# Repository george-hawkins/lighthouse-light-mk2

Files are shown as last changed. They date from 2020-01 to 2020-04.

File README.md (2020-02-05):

Lighthouse light mark 2
=======================

This project covers a mechanical alternative to my earlier [lighthouse light project](https://github.com/george-hawkins/lighthouse-light).

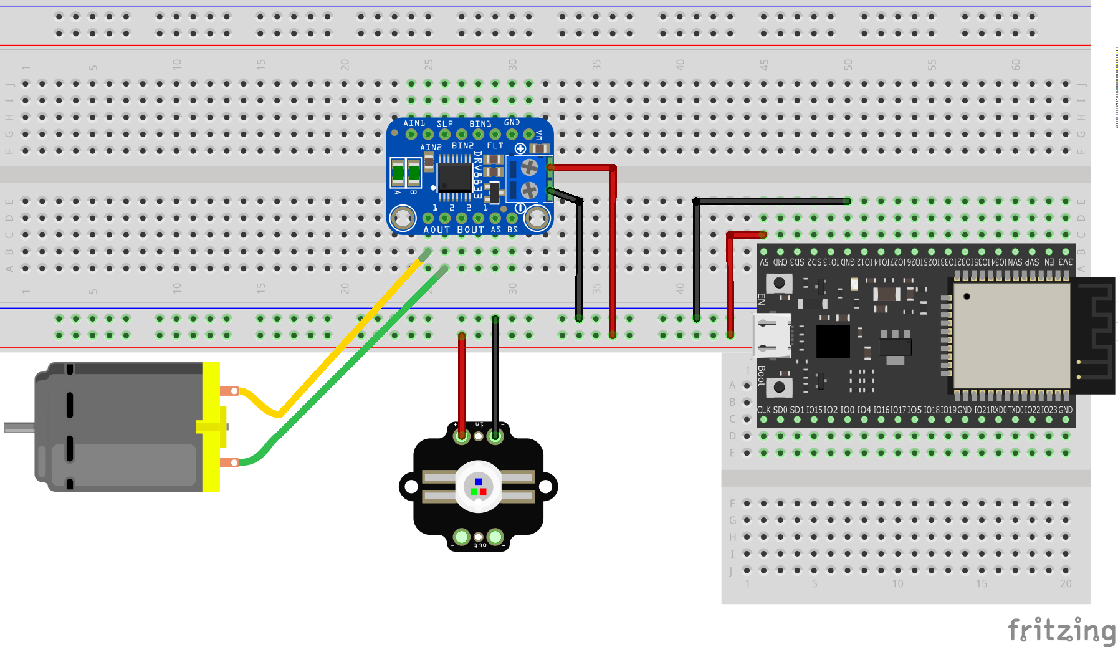
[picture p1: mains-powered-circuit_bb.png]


The [Fritzing](https://fritzing.org/home/) file for this circuit is [here](mains-powered-circuit.fzz).

Note: the Fritzing part for the ESP32-DevKitC was created by Hideaki Tominaga and can be found [here](https://ht-deko.com/delphiforum/?vasthtmlaction=viewtopic&t=1971.0#postid-3341).

Unfortunately, the ESP32-DevKitC is too wide to be mounted on a single standard breadboard - hence the need for the arrangement above where a smaller additional breadboard is used alongside the main one.

Misc
----

Also here, you can find:

* My [parts page](parts.md) for the main project here (and for the 3W RGB LED hookup and for a high current LiPo setup).
* My [hookup guide](3w-rgb-led-hookup-guide.md) for the Adafruit [3W RGB common anode LED](https://www.adafruit.com/product/2530).
* A [CSV file](digikey-leds-by-lumens.csv) of all the standard through-hole [discrete LEDs](https://www.digikey.com/products/en/optoelectronics/led-indication-discrete/105) that Digikey normally stock. Digikey just lists candella and viewing angle values for these LEDs, this CSV file includes a lumens value (calculated from the candella and angle values). The columns are _lumens_, _part number_, _millicandella_ and _viewing angle_. Some of the Digikey provided values appear to be wrong so you should double check any values in the relevant datasheet.
* My [guide](batteries.md) to batteries and in particular choosing parts for a setup where a lot of current is required.

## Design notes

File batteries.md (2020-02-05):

TLDR; if you want to draw more current, than supplied by the hobbyist li-ion cells from Adafruit and Sparkfun, then use a branded 18650 cell with a high C reading and built-in protection circuit along with a battery holder designed to accommodate the non-standard height of such cells.

---

Li-ion batteries are a borderline hobbyist component. Many electronics projects include a jokey disclaimer to the effect that the thing in question _may_ burn your house down. Li-ion batteries, if not handled correctly, definitely will burn your house down.

Li-ion batteries are inconventient to handle and inconventient to dispose of responsibly - but they can provide more power classic NiMH rechargeables (and don't suffer from the [memory effect](https://en.wikipedia.org/wiki/Memory_effect)).

However they're quite different from classic non-rechargeable alkaline batteries and NiMH rechargeables. These classic batteries don't need any supporting electronics and can be mishandled without any real dire consequences. Li-ion batteries in contrast will go on fire if mishandled and require a protection circuit to function safely.

The protection circuit typically do several things - it provides overcharging, overheating, shorting and undervoltage protection.

Overcharing, overheating and shorting will cause the battery to puff up (due to the build up of gasses within the cell) and eventually to catch fire.

Undervoltage in contrast is protecting the battery from you - with classic NiMH rechargeables you can just use them until they stop working and then recharge them. Li-ion batteries have a _nominal_ voltage of 3.7V, however when fully charged they provide about 4.2V - the voltage drops as the battery discharges. Eventually it'll reach 3V - if the voltage is allowed to drop below this point the battery will reach a state from which it cannot be charged.

The least consumer safe li-ion batteries are those used by [RC](https://en.wikipedia.org/wiki/Radio-controlled_model) hobbyists. These come wihout protection circuit or any kind of protective casing. It's up to separate circuitry in the RC vehicle to monitor the state of the battery.

In contrast the li-ion cells sold by hobbyist sites like Adafruit and Sparkfun come with a protection circuit as part of the battery. But with the exception of 18650 based cells (which we'll come to), they don't have any protective casing.

Finally the most consumer safe li-ion batteries are the powerbanks that you find everywhere for providing reserve power for your mobile phone and other portable consumer electronic devices. The li-ion cells are protected by a hard plastic case and the electronics provide the fixed 5V, that USB devices require, and limit the current.

These batteries may be safe and convenient but they're the least flexible for hobbyist projects. The fixed voltage, limited current and non-standard sizes don't make them great to work with (though you do find them being used in cheap robot projects. This [JetBot kit](https://www.sparkfun.com/products/15365) from Sparkfun uses one - but it also demonstrates the limitations of such powerbanks as the Nvidia Nano used in the project has to be run in a low-power mode due to the limited current, in contrast to this [JetBot kit](https://www.waveshare.com/jetbot-ai-kit-acce.htm) from Waveshare that uses 18650 batteries and can run the Nano at full power.

Most of the li-ion batteries provides by hobbyist sites come in completely non-standard shapes - the exception are those based on what are called [18650 cells](https://en.wikipedia.org/wiki/List_of_battery_sizes#Cylindrical_lithium-ion_rechargeable_battery).

If you crack open (not recommended) a powerbank you'll find it full of 18650 cells and if you crack open a Tesla battery pack you'll find more the 7 thousand of them.

They come in a standard form factor similar but larger than a classic AA battery. While they have a standard shape there are no end of variations with different [C ratings](https://oscarliang.com/lipo-battery-c-rating/) and different [mAh capacities](https://oscarliang.com/lipo-battery-guide/#capacity).

These cells aren't typically sold directly to consumers and, like all li-ion batteries, their tendency to catch fire is mishandled makes them very unpopular with postal services, e.g. the UK postal service will destroy your whole package if they find it contains loose li-ion cells, i.e. cells that are not built into or attached to an electronic device).

This makes them quite hard to buy. Most sites don't want to deal with the extra postage issues involves and even big electronic component sites like Mouser or Digikey, that carry every conceivable variant of everything else, don't really stock such batteries (they do sell a few as they act as distributors for the cells sold by Adafruit and Sparkfun and a few other hobbyist sites).

---

You can easily stick a thumb-tack into such a cell, shorting the internal layers and causing it to catch fire.

So you end up having to buy them from specialist sites.

They're heavily counterfieted, i.e. cheap no-name Chinese cells are repackaged to look like branded cells from Samsung etc. (whose cells look very generic anyway).

Manufacturers generally bundle unprotected cells together into packs and then provide protection and recharging circuitry for the full pack.

When using boards like the Adafruit [Feathers](https://www.adafruit.com/category/946) the recharging circuitry is provided by the board but you still need a protected cell.

So while 18650 cells are generally sold unprotected, you can buy them with a tiny [disc shaped protection circuit](https://www.banggood.com/1S-3_7V-18650-Lithium-Battery-Protection-Board-2_5A-Li-ion-BMS-with-Overcharge-and-Over-Discharge-Protection-p-1529056.html) attached to the base.

---

Spot welding - DIY

[Sunkko 737G 220V spot welding machine](https://www.banggood.com/SUNKKO-737G-220V-Battery-Spot-Welding-Hand-Held-Welding-Machine-with-Pulse-Current-Display-p-1310562.html) - US$110 from Banggood.

Battery holder - protected / unprotected.

Samsung Note, no-name hoverboards.

While many people do successfully build their own battery packs without apparent issue, the consensus seems to be that applying extreme heat, even momentarily, to something as already temperamental as a li-ion battery isn't recommended.

Buying the protection board separately gives you more flexibility - you can use any unprotected cell - but you have to make sure to match the maximum discharge current of the board to the the maximum discharge current supported by the cell.

MakeUseOf has a nice [introductory page](https://www.makeuseof.com/tag/18650-battery/) for 18650 batteries.

---

Memory Protection Devices (MPD) provide battery holders designed for protected 18650 cells:

* [BH-18650-PCD](https://www.digikey.com/product-detail/en/mpd-memory-protection-devices/BH-18650-PC/BH-18650-PC-ND/3029216) - battery holder without leads.
* [BH-18650-W](https://www.digikey.com/product-detail/en/mpd-memory-protection-devices/BH-18650-W/BH-18650-W-ND/3029217) - battery holder with leads.
* [BK-18650-PC2](https://www.digikey.com/product-detail/en/mpd-memory-protection-devices/BK-18650-PC2/BK-18650-PC2-ND/2079908) - battery holder with tabs to hold battery in-place and without leads.

The above links are to Digikey - these battery holders are available from many other suppliers, e.g. [Reichelt](https://www.reichelt.com/ch/en/Battery-holder-for-other-types-of-batteries/2/index.html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) (just select Memory Protection Digikey under the manufacturer filter).

Banggood knockoff of MPD battery holder for *protected* 18650, [with leads](https://www.banggood.com/DIY-1-Slot-18650-Battery-Holder-With-2-Leads-p-972775.html) and [without leads](https://www.banggood.com/DIY-Storage-Box-Holder-Case-For-1-x-18650-Rechargeable-Battery-p-1006063.html).

Adafruit [JST PH 2-pin 100mm cable with female connector](https://www.adafruit.com/product/261) or, if you need something longer, their [JST PH extension cable](https://www.adafruit.com/product/1131) (just chop off the unneeded end).

Banggood [Battery holder](https://www.banggood.com/1-Slots-18650-Battery-Box-Rechargeable-Battery-Holder-Board-for-1x18650-Batteries-DIY-kit-Case-p-1472104.html) for *unprotected* 18650.

Banggood [NCR18650B 3.7V 3400mAh protected 18650 battery](https://www.banggood.com/1PCS-NCR-18650B-3_7V-3400mAh-Protected-Rechargeable-Lithium-Battery-p-90678.html).

* AkkuShop Schweiz [NCR18650B 3400mAh protected 18650](https://www.akkushop-schweiz.ch/ch/panasonic-18650-li-ion-akku-mit-3400mah-und-eigener-schutzschaltung-ca.-68-x-18mm-beachten/) - Fr. 30.
* AkkuShop Schweiz [NCR18650B 2900mAh protected 18650](https://www.akkushop-schweiz.ch/ch/panasonic-ncr18650-pf-2900mah-pcb-geschuetzt/) - Fr. 26.
* Conrad DE [NCR18650B 3400mah protected 18650](https://www.conrad.de/de/p/panasonic-ncr18650b-spezial-akku-18650-li-ion-3-7-v-3400-mah-1009507.html) - EUR 19 (not listed on conrad.ch).

18650 Battery Store protected 18650 batteries:

* [Panasonic NCR18650B 3400mAh 4.9A](https://www.18650batterystore.com/Protected-p/panasonic-18650-protected.htm) - US$7.
* [Samsung 35E 18650 3500mAh 8A](https://www.18650batterystore.com/Samsung-18650-p/samsung-35e-protected.htm) - US$7
* [Sanyo NCR18650GA 3500mAh 10A](https://www.18650batterystore.com/Sanyo-18650-p/ncr18650ga-protected-pcb.htm) - US$8
* [Samsung 30Q 18650 3000mAh 15A](https://www.18650batterystore.com/Samsung-18650-p/samsung-30q-protected-pcb.htm) - US$9.

Note: in their [battery guide](https://www.18650batterystore.com/Best-18650-Battery-Guide-s/142.htm), the NCR18650B is described as "one of the best batteries on the market". However this page also lists the CDR (Continuous Discharge Rating) for every common 18650 battery and there you can see that the NCR18650B has the lowest CDR value - so if you need more than 5A, you'll need one of the other batteries.

See also [IMR Batteries](https://www.imrbatteries.com/18650-batteries/) for these 18650 batteries.

The easiest available source of protected 18650 batteries for consumers are 18650 batteries intended for use in flashlights, e.g. [Nitecore batteries](https://www.nitecorestore.com/18650-batteries-s/2532.htm). However these tend to be suprisingly expensive (and some of them come with odd feature like a USB port for direct charging).

Aliexpress TZT 1S boards:

* [3A](https://www.aliexpress.com/item/32803639402.html)
* [5A](https://www.aliexpress.com/item/32809288456.html)
* [7.5A, 10A and 15A](https://www.aliexpress.com/item/32956094047.html) - select 3MOS for 7.5A, 4MOS for 10A and 6MOS for 15A.

Banggood 1S boards:

* [2A](https://www.banggood.com/1S-3_7V-2A-li-ion-BMS-PCM-18650-Battery-Protection-Board-PCB-for-18650-Lithium-ion-li-Battery-p-1538099.html)
* [4A](https://www.banggood.com/1S-3_7V-4A-li-ion-BMS-PCM-18650-Battery-Protection-Board-PCB-for-18650-lithium-Battery-Double-MOS-p-1538089.html)

eBay:

* [1A to 12A](https://www.ebay.co.uk/itm/1S-Cell-PCB-BMS-18650-Protection-Board-Li-ion-Lithium-Battery/173955620419) - ships from UK.
* [5A, 10A and 15A](https://www.ebay.co.uk/itm/5-10-15A-1S-3-7V-18650-MOS-Li-ion-Lithium-Battery-Charging-BMS-Protection-Board/283300258134) - ships from China.

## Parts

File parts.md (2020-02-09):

Parts
=====

### 3W RGB common anode LED hookup

| Description | Quantity | Adafruit | Mouser | Digikey |
|---|---|---|---|---|
| 3W RGB common anode LED | 2 | [$3](https://www.adafruit.com/product/2530) | [$3](https://www.mouser.com/ProductDetail/485-2530) | [$3](https://www.digikey.com/product-detail/en/adafruit-industries-llc/2530/1528-2777-ND/9770538) |
| IRLB8721 N-channel power MOSFET | 3 | [$1.75](https://www.adafruit.com/product/355) | [$0.85](https://www.mouser.com/ProductDetail/942-IRLB8721PBF) | [$0.85](https://www.digikey.com/product-detail/en/infineon-technologies/IRLB8721PBF/IRLB8721PBF-ND/2127670) |
| ULN2803A - 8-channel Darlington driver | 1 | [$2](https://www.adafruit.com/product/970) | [$1.20](https://www.mouser.com/ProductDetail/511-ULN2803A) | [$1.20](https://www.digikey.com/product-detail/en/stmicroelectronics/ULN2803A/497-2356-5-ND/599591) |
| 5W 5&ohm; potentiometer | 1 | n/a | [$5.25](https://www.mouser.com/ProductDetail/774-026TB32R5A0B1A1) | [$5.25](https://www.digikey.com/product-detail/en/cts-electrocomponents/026TB32R5A0B1A1/CT2150-ND/203771) |
| 2W 5&ohm; resistor | 1 | n/a | [$0.20](https://www.mouser.com/ProductDetail/282-5.1-RC) | [$0.40](https://www.digikey.com/product-detail/en/yageo/FMP200JR-52-5R1/5.1ZCT-ND/2059023) |
| 2W 10&ohm; resistor | 1 | n/a | [$0.25](https://www.mouser.com/ProductDetail/282-10-RC) | [$0.35](https://www.digikey.com/product-detail/en/yageo/FMP200JR-52-10R/10ZCT-ND/2058964) |
| 2W 15&ohm; resistor | 1 | n/a | [$0.25](https://www.mouser.com/ProductDetail/282-15-RC) | [$0.35](https://www.digikey.com/product-detail/en/yageo/FMP200JR-52-15R/15ZCT-ND/2058972) |

Note: Yageo is Digikey and Xicon is Mouser - see the [AdaWiki partfinder](https://www.ladyada.net/wiki/partfinder).

### Shared

A 5V 2A power adapter, similar to this $7.50 [one](https://www.adafruit.com/product/1995) from Adafruit or pretty much any power adapter sold for the Raspberry Pi, must be 2A or more.

| Description | Quantity | Adafruit | Mouser | Digikey |
|---|---|---|---|---|
| 2200mAh 18650 Li-ion battery | 1 | [$10](https://www.adafruit.com/product/1781) | [$10](https://www.mouser.com/ProductDetail/485-1781) | [$10](https://www.digikey.com/product-detail/en/adafruit-industries-llc/1781/1528-1836-ND/5054543) |
| HUZZAH32 - ESP32 Feather Board | 1 | [$20](https://www.adafruit.com/product/3405) | [$20](https://www.mouser.com/ProductDetail/485-3405) | [$20](https://www.digikey.com/product-detail/en/adafruit-industries-llc/3405/1528-2181-ND/7244967) |

Similar [2600mAh 18650 battery](https://www.aliexpress.com/item/32822109986.html) from Aliexpress for $3.75.

Note that Mouser and Digikey will not ship li-ion batteries to retail customers in most regions or will apply restrictions (e.g. no air shipping).

### ESP32 alternatives

* $11 - [Olimex ESP32-DevKit-LiPo](https://www.olimex.com/Products/IoT/ESP32/ESP32-DevKit-LiPo/open-source-hardware).
* $21 - [SparkFun Thing Plus - ESP32 WROOM](https://www.sparkfun.com/products/15663).

There are no end of no-name ESP32 modules available on sites like Banggood and Espressif themselves produce the nice cheap [ESP32-DevKitC-32D](https://www.mouser.com/ProductDetail/356-ESP32-DEVKITC32D) - however the ESP32-DevKitC-32D and most of these other boards don't have a LiPo JST connector (and the no-name boards generally come with no documentation).

Note: the 32 is the original Espressif module, the 32D is the newer module and the 32U is the 32D with a connector for an external antennae rather than a builtin PCB antennae.

**Question:** the HUZZAH32 - ESP32 Feather Board provides separate Vbat and Vusb pins so you can easily construct a circuit that works off Vbat only. However the Olimex ESP32-DevKit-LiPo tries to be pin compatible with the ESP32-DevKitC-32D (which only supports power via 5V USB) - so, _if I read the schematic correctly_, you've just got the 5V input voltage pin and you'll either see 5V or 3.7V on this pin depending on whether you're using USB power or battery power. TODO: ask Olimex if there's anyway to construct a circuit such that you only get power via this pin if battery power is being used?

### Lighthouse mark 2

| Description | Quantity | Adafruit | Mouser | Digikey |
|---|---|---|---|---|
| Adafruit Pixie | 1 | [$15](https://www.adafruit.com/product/2741) |  [$15](https://www.mouser.com/ProductDetail/485-2741) | [$15](https://www.digikey.com/product-detail/en/adafruit-industries-llc/2741/1528-1538-ND/5804104) |
| Plastic gearbox motor - 200RPM | 2 | [$3](https://www.adafruit.com/product/3777) | [$3](https://www.mouser.com/ProductDetail/485-3777) | [$3](https://www.digikey.com/product-detail/en/adafruit-industries-llc/3777/1528-2589-ND/8687221) |
| Eccentric motor hub | 1 | [$1](https://www.adafruit.com/product/3880) | [$1](https://www.mouser.com/ProductDetail/485-3880) | [$1](https://www.digikey.com/product-detail/en/adafruit-industries-llc/3880/1528-2699-ND/9603622) |
| motor pulley | 1 | [$0.75](https://www.adafruit.com/product/3789) | [$0.75](https://www.mouser.com/ProductDetail/485-3789) | [$0.75](https://www.digikey.com/product-detail/en/adafruit-industries-llc/3789/1528-2602-ND/9342241) |
| DRV8833 motor driver breakout | 1 | [$5](https://www.adafruit.com/product/3297) | [$5](https://www.mouser.com/ProductDetail/485-3297) | [$5](https://www.digikey.com/product-detail/en/adafruit-industries-llc/3297/1528-1795-ND/6419360) |
| JST on/off switch | 1 | [$3](https://www.adafruit.com/product/3064) | [$3](https://www.mouser.com/ProductDetail/485-3064) | [$3](https://www.digikey.com/product-detail/en/adafruit-industries-llc/3064/1528-1679-ND/6022074) |
| motor mounting bracket | 1 | [$1.50](https://www.adafruit.com/product/3768) | [$1.50](https://www.mouser.com/ProductDetail/485-3768) | [$1.50](https://www.digikey.com/product-detail/en/adafruit-industries-llc/3768/1528-2593-ND/9092301) |

Alternative motor and wheel (use the wheel as a hub to which to attach things):

* $3.50 - [DC motor in micro servo body](https://www.adafruit.com/product/2941)
* $2.50 - [matching wheel for motor](https://www.adafruit.com/product/2744)

### JST cable assemblies

| Description | Quantity | Adafruit | Mouser | Digikey |
|---|---|---|---|---|
| 2-pin cable set | 1 | [$1.50](https://www.adafruit.com/product/2880) | [$1.50](https://www.mouser.com/ProductDetail/485-2880) | [$1.50](https://www.digikey.com/product-detail/en/adafruit-industries-llc/2880/1528-1596-ND/5875804) |
| 3-pin cable set | 1 | [$1.50](https://www.adafruit.com/product/1663) | [$1.50](https://www.mouser.com/ProductDetail/485-1663) | [$1.50](https://www.digikey.com/product-detail/en/adafruit-industries-llc/1663/1528-2108-ND/7035021) |
| 4-pin cable set | 1 | [$1.50](https://www.adafruit.com/product/578) | [$1.50](https://www.mouser.com/ProductDetail/485-578) | [$1.50](https://www.digikey.com/product-detail/en/adafruit-industries-llc/578/1528-1518-ND/5774321) |
| 5-pin cable set | 1 | [$1.50](https://www.adafruit.com/product/1664) | [$1.50](https://www.mouser.com/ProductDetail/485-1664) | [$1.50](https://www.digikey.com/product-detail/en/adafruit-industries-llc/1664/1528-2109-ND/7035022) |
| 6-pin cable set | 1 | [$1.50](https://www.adafruit.com/product/1665) | [$1.50](https://www.mouser.com/ProductDetail/485-1665) | [$1.50](https://www.digikey.com/product-detail/en/adafruit-industries-llc/1665/1528-2110-ND/7035023) |

I already have the 4 pin one.

There must be similar sets from companies other than Adafruit on Mouser and Digikey but I can't find them.

Servo cable extension (cut in two and use as an cable set) - [$2](https://www.adafruit.com/product/972).

Sugru family-safe black 3 pack:

* [$10](https://sugru.com/buy/family-safe-skin-friendly-formula-black-3-pack) direct from Sugru.
* [Fr. 10](https://www.galaxus.ch/en/s4/product/sugru-klebeknete-family-safe-3-stueck-schwarz-glues-12446856) from Galaxus.

Note: Sugru has a relatively short shelf life of 13 months so be aware of this when buying.

High-viscosity glue from a glue gun might be just as good for this project.

### Heatsinks

* [7x7x10mm heatsink](https://www.adafruit.com/product/1493) - $1 - plus [thermal tape](https://www.adafruit.com/product/1467) - $1.
* [14x14x8 heatsink with thermal tape](https://www.adafruit.com/product/3083) - $1.50

### Heat shrink tubing

* [40mm 1m clear (also other sizes, lengths and colors)](https://www.ebay.ie/itm/PVC-Heat-Shrink-Tubing-Wrap-RC-Battery-Pack-17mm-150mm-LiPO-NiMH-NiCd-UK/361275492238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) - GBP 2 - eBay UK based.
* [40mm 1m clear (also other sizes, lengths and colors)](https://www.ebay.ie/itm/17MM-103MM-Wide-PVC-Heat-Shrink-Tubing-Wrap-Lipo-Li-ion-NiCd-RC-Battery-Pack/390950012124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) - GBP 1 - eBay China based.
* [40mm 2m clear (also other sizes, lengths and colors)](https://www.ebay.ie/itm/17mm-103mm-PVC-Heat-Shrink-Tubing-Wrap-Lipo-Li-ion-Ni-MH-NiCd-RC-Battery-Pack/252489229777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) - GBP 1.60 - eBay China based.

### Power supplies

[Digikey 5V power adapters](https://www.digikey.com/products/en/power-supplies-external-internal-off-board/ac-dc-desktop-wall-adapters/130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)

[Mouser 5V power adapters](https://www.mouser.ch/Power/Power-Supplies/Plug-In-AC-Adapters/Wall-Mount-AC-Adapters/_/N-brwlvZscv7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)

Note: for whatever reason, Mouser will **not** ship power adapters to retail customers in the EU (and other countries).

[Raspberry Pi universal power supply](https://www.raspberrypi.org/products/raspberry-pi-universal-power-supply/) (comes with interchangeable plugs for all regions).

RS supply similar power adapters with region specific plugs, just go to [RS Components](https://www.rs-online.com/), choose your region (for North American, choose the Allied link rather than the RS link) and search for:

* T6717DV for a US style plug.
* T6716DV for an EU style plug.
* T6715DV for a UK style plug.

These are the standard Raspberry Pi power supplies and are available from many other online retailers - just search for the part numbers in Google shopping.

### Misc

* [DANIU 8 piece pliers set](https://www.banggood.com/8Pcs-Round-Beading-Nose-Pliers-Wire-Side-Cutters-Pliers-Tools-Set-p-1042930.html).
* [Stickers - 28 pieces](https://www.banggood.com/28pcs-Cartoon-Colourful-Reflection-DIY-Laser-Stickers-For-Suitcase-Skateboard-Laptop-Luggage-Sticker-p-1335114.html).
* [Riden UM34C USB voltage and current meter (with Bluetooth)](https://www.banggood.com/RIDEN-UM34UM34C-For-APP-USB-3_0-Type-C-DC-Voltmeter-Ammeter-Voltage-Current-Meter-Tester-p-1297185.html?ID=514816).

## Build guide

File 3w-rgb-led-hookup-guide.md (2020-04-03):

3W RGB LED hookup guide
=======================

This page covers hooking up the Adafruit [3W RGB common anode LED](https://www.adafruit.com/product/2530). Most devices, that sites like Adafruit and Sparkfun supply, can simply be powered directly from the MCU board that you're using in your project. However the 3W RGB LED is rather more complex to deal with as it draws significantly more power than an MCU board can supply.

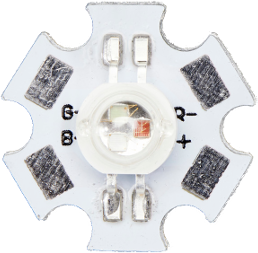
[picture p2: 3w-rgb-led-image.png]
3W RGB LED product image


TLDR; just jump to the breadboard diagram shown and set up the circuit shown making sure to use resistors with a suitable power rating.

---

Normally Adafruit has excellent hookup guides for all its parts, however all the guides for the 3W RGB LED involve using the [Prop-Maker FeatherWing](https://www.adafruit.com/product/3988) (which includes various other features, such as an amplifier and accelerometer). This "Wing" is designed to fit together with one of their [Feather series boards](https://www.adafruit.com/category/835). So it's not so clear how to hookup the 3W RGB LED directly to any arbitrary MCU board.

However the schematics etc. (as with all Adafruit boards) are available on GitHub. The EagleCAD files are [here](https://github.com/adafruit/Adafruit-Prop-Maker-FeatherWing-PCB). I opened the schematic in EagleCAD, converted it to an SVG with [eagle2svg](http://eagle.autodesk.com/eagle/ulp?q[title_or_author_or_description_cont]=svg) (an Eagle ULP to covert schematics to SVG) and cut out the part of the schematic that supports connecting a 3W RGB LED. The result can be seen below.

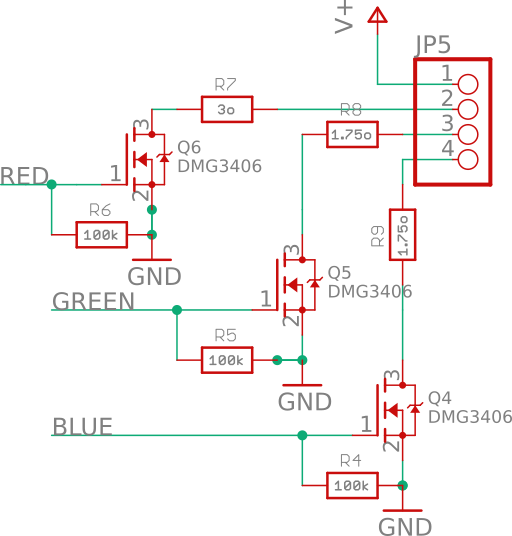
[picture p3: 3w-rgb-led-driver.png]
3W RGB LED driver schematic


The Prop-Maker FeatherWing uses a very simple circuit for controlling a 3W RGB LED. The 3 wires marked red, green and blue (on the left of the diagram) should be connected to PWM pins on your MCU board, the wire labeled V+ should be connected directly to your power source, typically a 3.7V LiPo battery (like [this](https://www.adafruit.com/product/1781)) and the four pads of your 3W RGB LED should be connected to the terminal marked as JP5 (1 to the LED's + terminal, 2 to R-, 3 to G- and 4 to B-).

The circuit itself consists of just a 100k&ohm; pull-down resistor for each PWM input followed by a [DMG3406](https://www.mouser.ch/ProductDetail/621-DMG3406L-7) MOSFET and a limiting resistor for the particular LED color that it controls. If you look at the [datasheet](https://cdn-shop.adafruit.com/product-files/2530/FD-3RGB-Y2.pdf) for the RGB LED you'll see that the forward voltage for red is 2.5V while it's 3.6V for green and blue, hence the different limiting resistors - 3&ohm; for red and 1.75&ohm; for green and blue.

As you can see in the schematic, the pull-down resistors are marked as 0603 and the limiting resistors are marked as 1206 - 0603 resistors are usually 0.1W and 1206 resistors are usually 0.25W (see [resistor sizes and packages](http://www.resistorguide.com/resistor-sizes-and-packages/)). 0.1W is fine for the 100k&ohm; pull-down resistors and 0.25W is fine for the 1.75&ohm; blue and green limiting resistors but the red limiting resistor is probably at least 0.5W, if not 1W (see down below for more details).

If you look at the [Prop-Maker FeatherWing guide](https://learn.adafruit.com/adafruit-prop-maker-featherwing?view=all) you can clearly see this circuit in the guide's hi-resolution image of the top of the board:

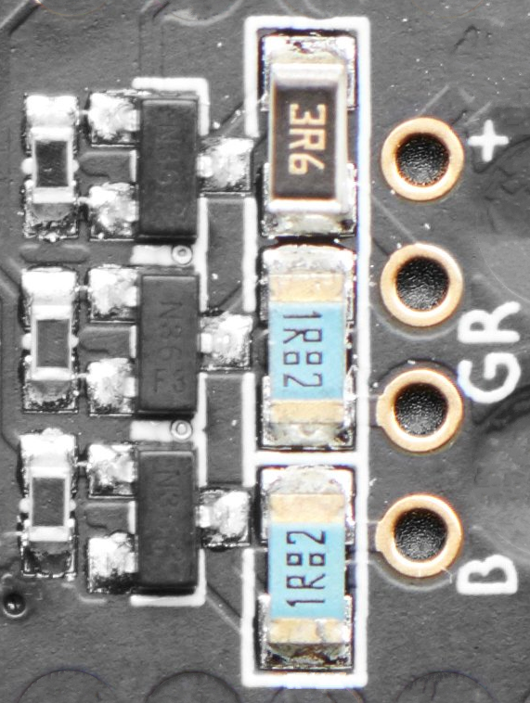
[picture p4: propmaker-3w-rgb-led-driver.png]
[](https://cdn-learn.adafruit.com/assets/assets/000/069/373/original/adafruit_products_PropMakerFeatherWingTop.jpg)

The pull-down resistors are to the left, then the three pin MOSFETs, then the larger limiting resistors and finally pads for connecting the 3W RGB LED.

If you look at the [complete schematic](https://learn.adafruit.com/assets/69243) and the [logic pins section](https://learn.adafruit.com/adafruit-prop-maker-featherwing?view=all#logic-pins-2-5) of the guide, it's clear that you just connect the PWM inputs directly to pins on your MCU while V+ is connected either directly to your battery or to a pin on your MCU that provides the battery voltage directly.

You should **not** attempt to power it off one of the logic pins on your MCU board - this will destroy the pin as the older 5V Arduinos can only handle about 40mA per GPIO pin and the newer 3.3V ARM-based MCU boards can typically only handle at most 10mA per pin (and around 200mA and 130mA respectively for all such pins combined).

Note: a classic Arduino UNO can power a basic 20mA LED directly from a GPIO pin but however newer 3.3V ARM-based MCU boards can't provide enough current to drive them directly at full power. Instead they'd need to use a transisor to get full brightness out of these basic LEDs. To see how to drive a 20mA LED using a transistor see this [example](https://learn.sparkfun.com/tutorials/installing-libmraa-on-ubilinux-for-edison#the-circuit) from Sparkfun or this slightly different schematic in this ElectricalEngineering StackExchange [answer](https://electronics.stackexchange.com/a/60868/27099) (that doesn't invovle a current limiting resistor on the GPIO pin).

Creating the 3W LED driver circuit with through-hole components
---------------------------------------------------------------

So as we can see the necessary circuit is very simple. Now let's look at how to reproduce it on a breadboard.

The following two Adafruit guides provided all the information needed to produce the circuit below:

* [Adafruit transistors 101](https://learn.adafruit.com/transistors-101?view=all) - in particular see the FETs section, the "How do I pick a transistor for the job?" section and the "Driving a LED Strip" example (using Darlington transistors).
* The usage section of the [RGB LED strips guide](https://learn.adafruit.com/rgb-led-strips?view=all#usage) - the examples here are better as they show using MOSFETs ([IRLB8721](https://www.adafruit.com/product/355)) as well as Darlington transistors ([TIP120](https://www.adafruit.com/product/976)).

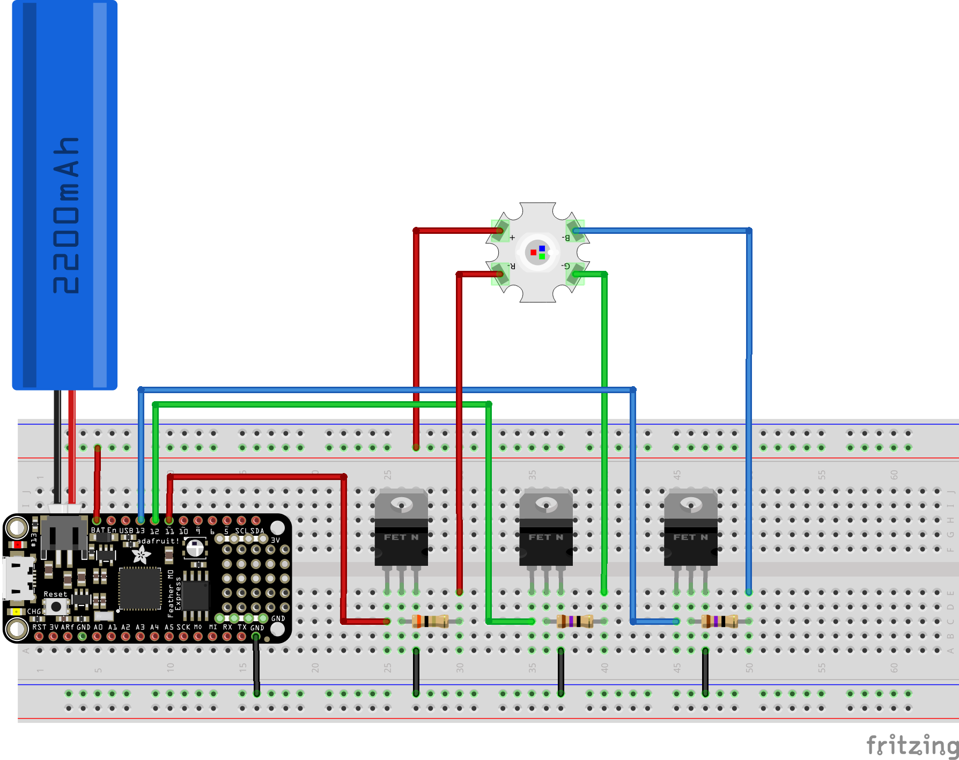
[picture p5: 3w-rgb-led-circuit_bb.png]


The [Fritzing](https://fritzing.org/home/) file for this circuit is [here](3w-rgb-led-circuit.fzz).

In order to connect the 3W RGB LED you could solder jumper wires onto its pads or you could use jumper wires with alligator clips at one end (like [these](https://www.adafruit.com/product/3448) from Adafruit).

This circuit uses a 3.7V battery.

* [1W 3&ohm; resistor](https://www.digikey.com/product-detail/en/yageo/FMP100JR-52-3R/3.0WCT-ND/2058923) - $0.40
* [1/4W 1.8&ohm; resistor](https://www.digikey.com/product-detail/en/yageo/CFR-25JB-52-1R8/1.8QBK-ND/154) - $0.10 - 1.8&ohm; is as close as you can get to 1.75&ohm; for through-hole resistors.

**Important:** when using 3.7V LiPo it's fine to use normal 0.25W resistors for the 1.75&ohm; limiting resistors for green and blue but you'll need to use a higher power 1W resistor for the 3&ohm; limiting resistor for red (see below for more details).

Or should the 3&ohm; really be a 4.9&ohm;? See my [forum question](https://forums.adafruit.com/viewtopic.php?f=47&t=160899). If so a [1W 5.1&ohm; resistor](https://www.digikey.com/product-detail/en/yageo/KNP1WSJR-52-5R1/5.1GCCT-ND/2813153) is about the closest through-hole resistor you can get.

Note: I calculate 1.71&ohm; for the green/blue resistor - you can't closer than 1.8&ohm; to that.

And if you look at the image of an actual board the SMD codes of the green and blue resistors are near enough to what you'd expect (1R82 is 1.82&ohm;) but red is 3R6, i.e. 3.6&ohm; which doesn't get is neither the 3&ohm; of the schematic nor the 4.9&ohm; I calculate below. 3.6&ohm; implies a supply current of 0.35 * 3.6 + 2.5 = 3.8V.

TODO: this is all so odd that it's probably best to work out suitable resistors with a real LED and the 5&ohm; potentiometer that's mentioned later.

Note: that 3.7V LiPo batteries are actually 4.2V when fully charged (see the [voltages page](https://learn.adafruit.com/li-ion-and-lipoly-batteries/voltages) of the Adafruit guide to LiPo batteries for more on the discharge profile of such batteries).

TODO: is there 5V on Vbat when recharging the LiPo via USB? If so will this cause problems for recharging if the source is low amps, e.g. 500mA for a laptop USB port, or will it cause problems if the source is high amps, e.g. a 2A power adapter, i.e. enough to charge and drive the LED circuit at 5V (despite the limiting resistors being for just 4.2V)? This would be kind of stupid - it'd mean your circuit has to be 3.2V to 5V tolerant.

**Important:** most breadboards are rated for about 1A at 5V - so this circuit is operating near to the limits of what a breadboard can handle. If you intend using this circuit over an extended period you should use something like an Adafruit [perma-proto board](https://www.adafruit.com/product/591) or a [perfboard](https://www.adafruit.com/product/2670) instead and solder things in place permanently.

Pull-down resistors
-------------------

The Prop-Maker FeatherWing schematic includes pull-down resistors while the circuit here does not (and neither does the [example](https://learn.adafruit.com/rgb-led-strips?view=all#usage) in the RGB LED strips guide).

The general consensus is that you should include pull-down resistors on a daughter board like the FeatherWing so that the MOSFETs behave if nothing is connected to the base, e.g. if the PWM pins are left unconnected. However you can do without the pull-down resistors if you're sure your MOSFETs will definitely be fully connected up, as here, and there's a single power source for both your MCU board and the current controlled by the MOSFETs (as is also the case here), i.e. when the MCU board is unpowered so is the rest of the circuit.

The only time as which the lack of pull-down resistors might be an issue is when the MCU board is reset - during this phase the state of the PWM pins is undefined and may result in the MOSFETs blinking on for a moment. That the LEDs blink momentarily isn't really an issue but it might be when controlling something else, e.g. motors.

The necessary 10k&ohm; are cheap and a trivial addition so including them if you feel you need them isn't much of an issue.

See the Adafruit [pulse room guide](https://learn.adafruit.com/pulse-room?view=all#led-driver) for a LED driver circuit that does use a pull-down resistor.

Code
----

The [Prop-Maker FeatherWing guide](https://learn.adafruit.com/adafruit-prop-maker-featherwing?view=all) includes code sections for both Arduino environment C and for CircuitPython.

The Arduino C [3W RGB LED example](https://learn.adafruit.com/adafruit-prop-maker-featherwing?view=all#3-watt-led-3-15) can be used unchanged with the circuit here if you use the same MCU pins as seen in the initial `#define` section. This example does not require any additional libraries.

Similarly the CircuitPython [example](https://learn.adafruit.com/adafruit-prop-maker-featherwing?view=all#3-watt-led-4-14) does not require anything beyond the core CircuitPython modules and can be used unchanged if you use the D11, D12 and D13 pins as setup when the `red`, `green` and `blue` variables are declared.

Using Darlington transistors
----------------------------

Instead of the MOSFETs you could use Darlington transistors (like this [TIP120 3 pack](https://www.adafruit.com/product/976) from Adafruit). These are cheaper but far less efficient and the voltage drop across them is significant (which is a noticeable issue here when using a 3.7V power source but less so when using 5V).

While Darlington transistors are less efficient you can get eight of them bundled up in a very convenient breadboardable DIP chip - the [ULN2803](https://www.adafruit.com/product/970) (which, at $2 from Adafruit or $1.20 from Mouser or Digikey, is very cheap as well as convenient).

TODO: circuit with ULN2803 - see the Adafruit [sign driver guide](https://learn.adafruit.com/led-neon-signs?view=all#build-the-sign-driver) for a good example. Work out suitable resistors - the voltage drop of the ULN2803 depends on the current so wire it up the same resistors as with the MOSFETs, work out the actual voltage seen by the LED and the limiting resistors and work out proper limiting resistor value for this setup. See how hot the ULN2803 gets.

Try starting with just a 15&ohm; resistor, i.e. no LED, then measure the current, then move down to 10&ohm; and 5&ohm; with 5&ohm; potentiometer is series (see 2W parts down below) and work out resistance needed to achieve 350mA.

**Question:** if you can get Darlington transistors in a convenient DIP format then can't you also get MOSFETs in a similar format?

The short answer is **no**.

The ULN2803 has been around forever and continues to be produced. The DIP format is very convenient for hobbyists to work with. However the world that drives the development of components has moved to SMD and in this world people are happy, as with the Prop-Maker FeatherWing, to use individual SMD MOSFETs as all the hard work (with the fiddly work of placing them being handled by [pick-and-place machines](https://en.wikipedia.org/wiki/Pick-and-place_machine).

You can buy what are called LED driver chips (the kind of thing that's used in a typical LED lightbulb) however most of these are SMD. There are a few LED drivers in DIP format, like the TI [TLC59211IN](https://www.mouser.ch/ProductDetail/595-TLC59211IN) that use [DMOS](https://en.wikipedia.org/wiki/Power_MOSFET), i.e. MOSFETs. But these can't sink more than 200mA per output which is significantly less than the 350mA needed for the 3W RGB LED. If you could get 200mA through-hole LEDs this might still be an interesting chip to use in projects - however 20mA seems to be the limit for commonly available through-hole LEDs (you can find higher current ones but for the ones I found the higher current, for whatever reason, doesn't seem to translate to an interesting increase in lumens).

TODO: are there through-hole 200mA LEDs anywhere that do produce a significant numbers of lumens, e.g. in the 10+ lumens range? I asked about this [here](https://forums.adafruit.com/viewtopic.php?f=8&t=160984) of the Adafruit forums.

Alternatives
------------

The 3W RGB LED is US$3 and the MOSFETs and resistors add additional cost (the MOSFETs are $1.75 each from Adafruit but considerably cheaper at $0.85 from e.g. [Digikey](https://www.digikey.com/products/en?keywords=IRLB8721PBF) or [Mouser](https://www.mouser.com/ProductDetail/942-IRLB8721PBF)). And the resistors will have to be ordered from somewhere like Mourser or Digikey as these low Ohm resistors aren't carried by hobbyist sites like Adafruit or Sparkfun.

So this comes to a minimum of $3 + (3 x $0.85) + (3 x $0.10) = $5.85 (not including postage). You're not far off the $10 cost of the Prop-Maker FeatherWing (especially when you factor in your time and effort as a cost).

Another alternative is the [Adafruit Pixie](https://www.adafruit.com/product/2741) a 3W smart pixel with all necessary components built-in. At $15, it's considerably more expensive than building the circuit above but you save assembly time and the Pixie has additional useful features such as temperature cut-off.

Resistors for different voltages
--------------------------------

The circuits above assume you're using a 3.7V LiPo battery to power things.

Alternatively you could use achive a similar voltage with a [3 x AA battery holder](https://www.adafruit.com/product/3287) and standard NiMH rechargeable AA batteries (giving a nominal voltage of 3.6V). If you use standard non-rechargeable alkaline AA batteries then you can't get quite so close to the 3.7V of a LiPo - if you use the 3 x battery holder with alkalines this will give you a nominal voltage of about 4.5V and if you use a [2 x AA battery holder](https://www.adafruit.com/product/4193) then this will give you a nominal voltage of just 3V.

Most MCU boards can also be power via USB using a 5V power adapter. The power consumption of both the the MCU board and a 3W RGB LED is greater than the 500mA that the USB ports of your average laptop or PC can deliver and the 1A delivered by the some USB power adapters. So you should use a power adapter that can deliver at least 2A (something like this [one](https://www.adafruit.com/product/1995) from Adafruit - US plug only - that delivers 2.5A).

If you get rid of the LiPo battery in the main MOSFET circuit above and use such a 5V power adapter instead then you'll also need different resistors.

Both the Adafruit ["All about LEDs"](https://learn.adafruit.com/all-about-leds?view=all) page and the more specific Sparkfun ["LED current limiting resistors"](https://www.sparkfun.com/tutorials/219) page cover what you need to know to calculate the resistor values.

The important thing is the equation _R = (V<sub>s</sub> - V<sub>f</sub>) / i_ where _i_ is forward current, _V<sub>f</sub>_ is forward voltage _V<sub>s</sub>_ is supply voltage and _R_ is the resistance that we're solving for.

If we look at the [datasheet](https://cdn-shop.adafruit.com/product-files/2530/FD-3RGB-Y2.pdf) for the 3W RGB LED we can see that _i_ is 350mA and _V<sub>f</sub>_ is 2.5V for red and 3.6V for green and blue.

So if _V<sub>s</sub>_ is 5V, e.g. a USB power adapter, then the resistences we need are:

* Red = (5 - 2.5) / 0.35 = 7.14&ohm; (the nearest standard resistor is 7.5&ohm;).
* Green = (5 - 3.6) / 0.35 = 4&ohm;.
* Blue = 4&ohm; (the same as blue).

**Important:** when using 5V you can't use normal 0.25W resistors for these limiting resistors. You'll need a resistor with a 1W power rating for red and 0.5W for blue and green (see below for more details).

This corresponds, as you'd expect, with this values Rick from Adafruit Support quotes in this [forum answer](https://forums.adafruit.com/viewtopic.php?f=47&t=79083#p400741).

If we change _V<sub>s</sub>_ to 3.7V, e.g. a LiPo battery, then we get:

* Red = (3.7 - 2.5) / 0.35 = 3.4&ohm;.
* Green/blue = (3.7 - 3.6) / 0.35 = 0.3&ohm;.

TODO: get rid of all calculations based on 3.7V and just leave the 4.2V ones.

Or if we change _V<sub>s</sub>_ to 4.2V, the fully charged voltage of a 3.7V LiPo battery, then we get:

* Red = (4.2 - 2.5) / 0.35 = 4.86&ohm;.
* Green/blue = (4.2 - 3.6) / 0.35 = 1.71&ohm;

So the 1.75&ohm; value for green and blue looks OK, if we use a supply voltage of 4.2V, but the red value here looks quite different to the 3&ohm; used in the Prop-Maker FeatherWing.

**TODO:** you can calculate the implied supply voltage, given the limiting resistor value, using _V<sub>s</sub> = iR + V<sub>f</sub>_. If you use 3&ohm; and 1.75&ohm; you get:

* Red = 0.35 * 3 + 2.5 = 3.6V
* Green/blue = 0.35 * 1.75 + 3.6 = 4.2V

So these values are different and don't even imply some consistent voltage other than 3.7V. **What's going on here?**

If you're using alkalines batteries then it's left as an exercise to calculate suitable values for them.

Resistor power rating
---------------------

The resistors that you use in most simple electronics projects are 0.25W resistors (like those in the [Sparkfun resistor kit](https://www.sparkfun.com/products/10969) or those in the Adafruit [resistor category](https://www.adafruit.com/category/837)). However in this situation were dealing with rather more power than usual so we need a higher wattage for red when using a 3.7V LiPo and higher wattage resistors for all colors when using 5V.

Each color in our 3W RGB LED draws 350mA. The voltage drop across red is 2.5V (see _V<sub>f</sub>_) above and 3.6V for green and blue.

If we're using a 5V power source this means the voltage drop across the limiting resistor is (5 - 2.5) = 2.5V for red and (5 - 3.6) = 1.4V for green and blue.

So as _W = VI_ (power = voltage * current) then we get:

* Red = 2.5 * 0.35 = 0.875W
* Green/blue = 1.4 * 0.35 = 0.49W

So we need a 1W resistor for red and 0.5W resistors for green and blue.

If we're using a 3.7V power source then we get:

* Red = (3.7 - 2.5) * 0.35 = 0.42W
* Green/blue = (3.7 - 3.6) * 0.35 = 0.035W

So we need a 0.5W resistor for red and a normal 0.25W resistor for green and blue.

But if instead of 3.7V we use 4.2V, i.e. the voltage of a fully charged LiPo, we get:

* Red = (4.2 - 2.5) * 0.35 = 0.6W
* Green/blue = (4.2 - 3.6) * 0.35 = 0.2W

So we're still OK with normal 0.25W resistor for green and blue but a 1W resistor for red is probably necessary.

Are these 3W RGB LEDs really that bright?
-----------------------------------------

So how do these 3W RGB LEDs compare with the brightest of the usual through-hole LEDs? It turns out it all depends what you mean by bright!

If you look at the Adafruit product description for their 3W RGB LED you'll see:

> Each of the red, green, and blue dice can handle continuous ~350mA current draw (with peaks of 1000mA). The light output is 110 lumens (110,000 millicandela) total.

So the combined current draw of the three colors is around 1A and the total light output is about 110lm which Adafruit say is equivalent to 110cd.

However converting from lumens to candela isn't a simple one-to-one conversion as Adafruit seem to suggest. It depends on what's called the apex angle and the conversion is only one-to-one if the apex angle is ~65.5&deg;. However according to the LED's datasheet its apex angle is 120&deg; - so 110lm and an apex angle of 120&deg; converts to just 35cd (see the RapidTables [lumens-to-candela calculator](https://www.rapidtables.com/calc/light/lumen-to-candela-calculator.html)).

If you then look at the product page for the Adafruit [super-bright white 5mm LED](https://www.adafruit.com/product/754) you can see:

> * 15,000 mcd minimum brightness
> * Viewing Angle : +/-12 degrees
> * Maximum continuous current: 20 mA

They say you get 15cd minimum _brightness_ and that for just 20mA.  So it seems like just 3 of these will achieve more brightness than the 3W RGB LED and for only 60mA in total (which an MCU board can deliver directly without requiring MOSFETs etc.).

So what's going on here? It turns out that when engineers talk about lumens and candella, they're talking about intensity and light output in a far more precise manner than when people use the word "brightness" in everyday language. For us, it's generally not really useful to compare one candela value with another if you don't also talk about the apex angle. If you're just interested in the total amount of light output by the LED then it's more useful to talk in terms of lumens. So instead of converting things to candela, as above, let's convert to lumens.

The 15cd and an apex angle of 24&deg; (2 x 12&deg;) for the super-bright white 5mm LED, converts to just 2lm (see the RapidTables [candela-to-lumens calculator](https://www.rapidtables.com/calc/light/candela-to-lumen-calculator.html)).

So the total light output of the 3W RGB LED, with its 110lm, is 55 times that of the brightest of Adafruit's through hole LED - that sounds a bit more impressive.

For much more on the relationship between candela and lumens see CompuPhase's [Candela, Lumen, Lux: the equations](https://www.compuphase.com/electronics/candela_lumen.htm). In short you can sum it up as follows. The total light output of a laser pointer is fairly low but the light it does output is very focused - the intensity of this light is very high but it just lights up a tiny point. So a laser pointer has a very high candela value but a low lumens value. In contrast a light bulb outputs a lot of light but in all directions (unlike the focused beam of a laser pointer) so it lights up a whole room but the light isn't very intense. So a light bulb has a far higher lumens value but a relatively low candela value.

If you look at Mouser or Digikey you can find 20mA white LEDs (like [this](https://www.mouser.ch/ProductDetail/941-C503DWANCCBEB152)) that go up to 48cd and red LEDs, which for whatever reason are produced with much higher candela values than blue or green LEDs, (like [this](https://www.mouser.ch/ProductDetail/78-VLCS5830)) that go up to 65cd. However if you look at such products you'll see that their apex angles are tiny. For standard 20mA LEDs the higher the candela value the lower the apex angle and once you take this into account you can see that all such LEDs tend to produce much the same light output - around 1 or 2lm.

TODO: it seems to me that viewing angle and apex angle are equivalent - is this definitely correct?

---

Misc
----

* [Sparkfun 1/4 Watt resistor kit](https://www.sparkfun.com/products/10969)

* ULN2803A at [Adafruit](https://www.adafruit.com/product/970) / at [Mouser](https://www.mouser.ch/ProductDetail/511-ULN2803A)

---

Parts:

* 2W 5&ohm; resistor - https://www.digikey.com/product-detail/en/yageo/PNP5WVJT-73-5R/YAG1206CT-ND/4135362
* 2W 10&ohm; resistor - https://www.digikey.com/product-detail/en/yageo/FMP200JR-52-10R/10ZCT-ND/2058964
* 2W 15&ohm; resistor - https://www.digikey.com/product-detail/en/yageo/FMP200JR-52-15R/15ZCT-ND/2058972

* 5&ohm; potentiometer - https://www.mouser.com/ProductDetail/774-026TB32R5A0B1A1 - $5.23
* 2W 5.1&ohm; resistor - https://www.mouser.com/ProductDetail/282-5.1-RC
* 2W 10&ohm; resistor - https://www.mouser.com/ProductDetail/282-10-RC
* 2W 15&ohm; resistor - https://www.mouser.com/ProductDetail/282-15-RC

Note: Yageo is Digikey and Xicon is Mouser - see the [AdaWiki partfinder](https://www.ladyada.net/wiki/partfinder).

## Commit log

2020-01-05 Added 3w-rgb-led-driver.svg.
2020-01-05 Added PNG for 3w-rgb-led-driver.svg so it displays at desired scale.
2020-01-06 Added MOSFET and transistor links.
2020-01-08 Initial hookup guide for 3W RGB LED.
2020-01-08 Added 3W RGB hookup guide.
    [3w-rgb-led-circuit.fzz]
2020-01-08 Added comparison to cost of Prop-maker.
2020-01-09 Added comparison between 3W RGB LEDs and standard 20mA through-hole LEDs.
2020-01-09 Reordered MOSFET wiring into nicer RGB order.
    [3w-rgb-led-circuit.fzz]
2020-01-12 Filled in lots of extra details for hooking up a 3W RGB LED.
2020-01-12 Added resistor links for ULN2803 experiments.
2020-01-13 Added more resistor details.
2020-01-13 More minor notes on battery voltages.
2020-01-13 More resistence notes.
2020-01-15 Added pull-down resistor section and code section.
2020-01-15 Added link to sign driver guide.
2020-01-15 Added heatsink and heat shrink parts.
2020-01-15 Updated Fritzing layout.
    [3w-rgb-led-circuit.fzz]
2020-01-18 Added note on powering basic 20mA LEDs from GPIO pins. And added digikey-leds-by-lumens.csv.
    [digikey-leds-by-lumens.csv]
2020-01-18 Added question about 5V pin of Olimex ESP32 board.
2020-01-22 Fixed ESP32 link.
2020-02-02 Added initial Fritzing files for mains powered circuit.
    [mains-powered-circuit.fzz]
2020-02-05 Changed spaces to commas in digikey-leds-by-lumens.csv.
    [digikey-leds-by-lumens.csv]
2020-02-05 Added column headers to digikey-leds-by-lumens.csv.
    [digikey-leds-by-lumens.csv]
2020-02-15 Added ESP32-MicroPython-setup.md.
2020-02-16 Reviewed and cleaned up ESP32-MicroPython-setup.md.
2020-02-16 Added reference to the ESP32 quick reference.
2020-03-04 Added Linux notes to ESP32-MicroPython-setup.md.
2020-05-16 Moved ESP32-MicroPython-setup.md into https://github.com/george-hawkins/micropython-notes
